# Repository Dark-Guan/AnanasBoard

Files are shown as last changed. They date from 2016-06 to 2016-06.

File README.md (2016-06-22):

# AnanasBoard
AnanasBoard is Designed for Stepper Closeloop Control.

<a rel="license" href="http://creativecommons.org/licenses/by/4.0/">
</a><br />本作品采用<a rel="license" href="http://creativecommons.org/licenses/by/4.0/">知识共享署名 4.0 国际许可协议</a>进行许可。

如果你认为我做的这些对你来说是有价值的, 并鼓励我进行更多开源和免费的开发. 那你可以资助我, 就算是一杯咖啡...

If you find my work useful and you want to encourage the development of more free resources, you can do it by donating...

<a rel="donate1" href="https://www.paypal.com/cgi-bin/webscr?cmd=_s-xclick&hosted_button_id=8GQHVZ7YR8NZE">
PalpayDonate</a>

<a rel="donate2" href="https://raw.githubusercontent.com/Dark-Guan/AnanasBoard/master/apcazu6ntbjy04py09.png">
Alipay</a>

##feature

1. AMS5600 and Quadrature Encoder Supported  
2. Intelligent Tuning of the Motor Current  
3. Up to 30Khz Pulse Input Supported  
4. Up to 60Khz Stepper Driver PWM with Trapezoid Acceleration  
5. Internal PID Speed Controller  

##driver
1. A4988 and Drv8825 supported.
2. PWM DA function supported.With the  Tale:
    *PWM frequence needs to be up to 10Khz*

| IC| divider resistance | Capacitance | 5V| 3.3V
| --- | --- | --- | --- | ---
| A4988 | 10KOhm | 0.1uf | 4.7KOhm | 10KOhm
| drv8825 | 10KOhm | 0.1uf | 2.7KOhm | 3.3KOhm

circuit: voltage division circuit with a Capacitance(0.1uf)  
More Info : _[A4988](http://www.allegromicro.com/~/media/Files/Datasheets/A4988-Datasheet.ashx?la=zh-CN) and [Drv8825](http://www.ti.com/lit/ds/symlink/drv8825.pdf)datasheet_.  

# Eagle

Eagle 7.2 Used

# SoftWare
https://git.oschina.net/GaryPillow/Ananas
## back up
https://github.com/Dark-Guan/Ananas

https://github.com/Dark-Guan/Ananas/tree/master/binary

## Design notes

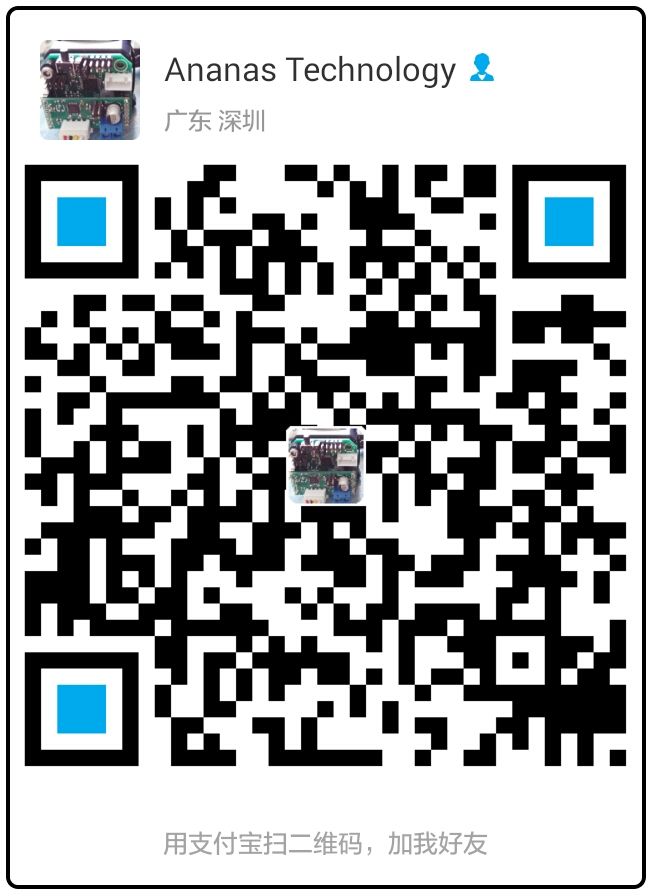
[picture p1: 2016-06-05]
apcazu6ntbjy04py09.png

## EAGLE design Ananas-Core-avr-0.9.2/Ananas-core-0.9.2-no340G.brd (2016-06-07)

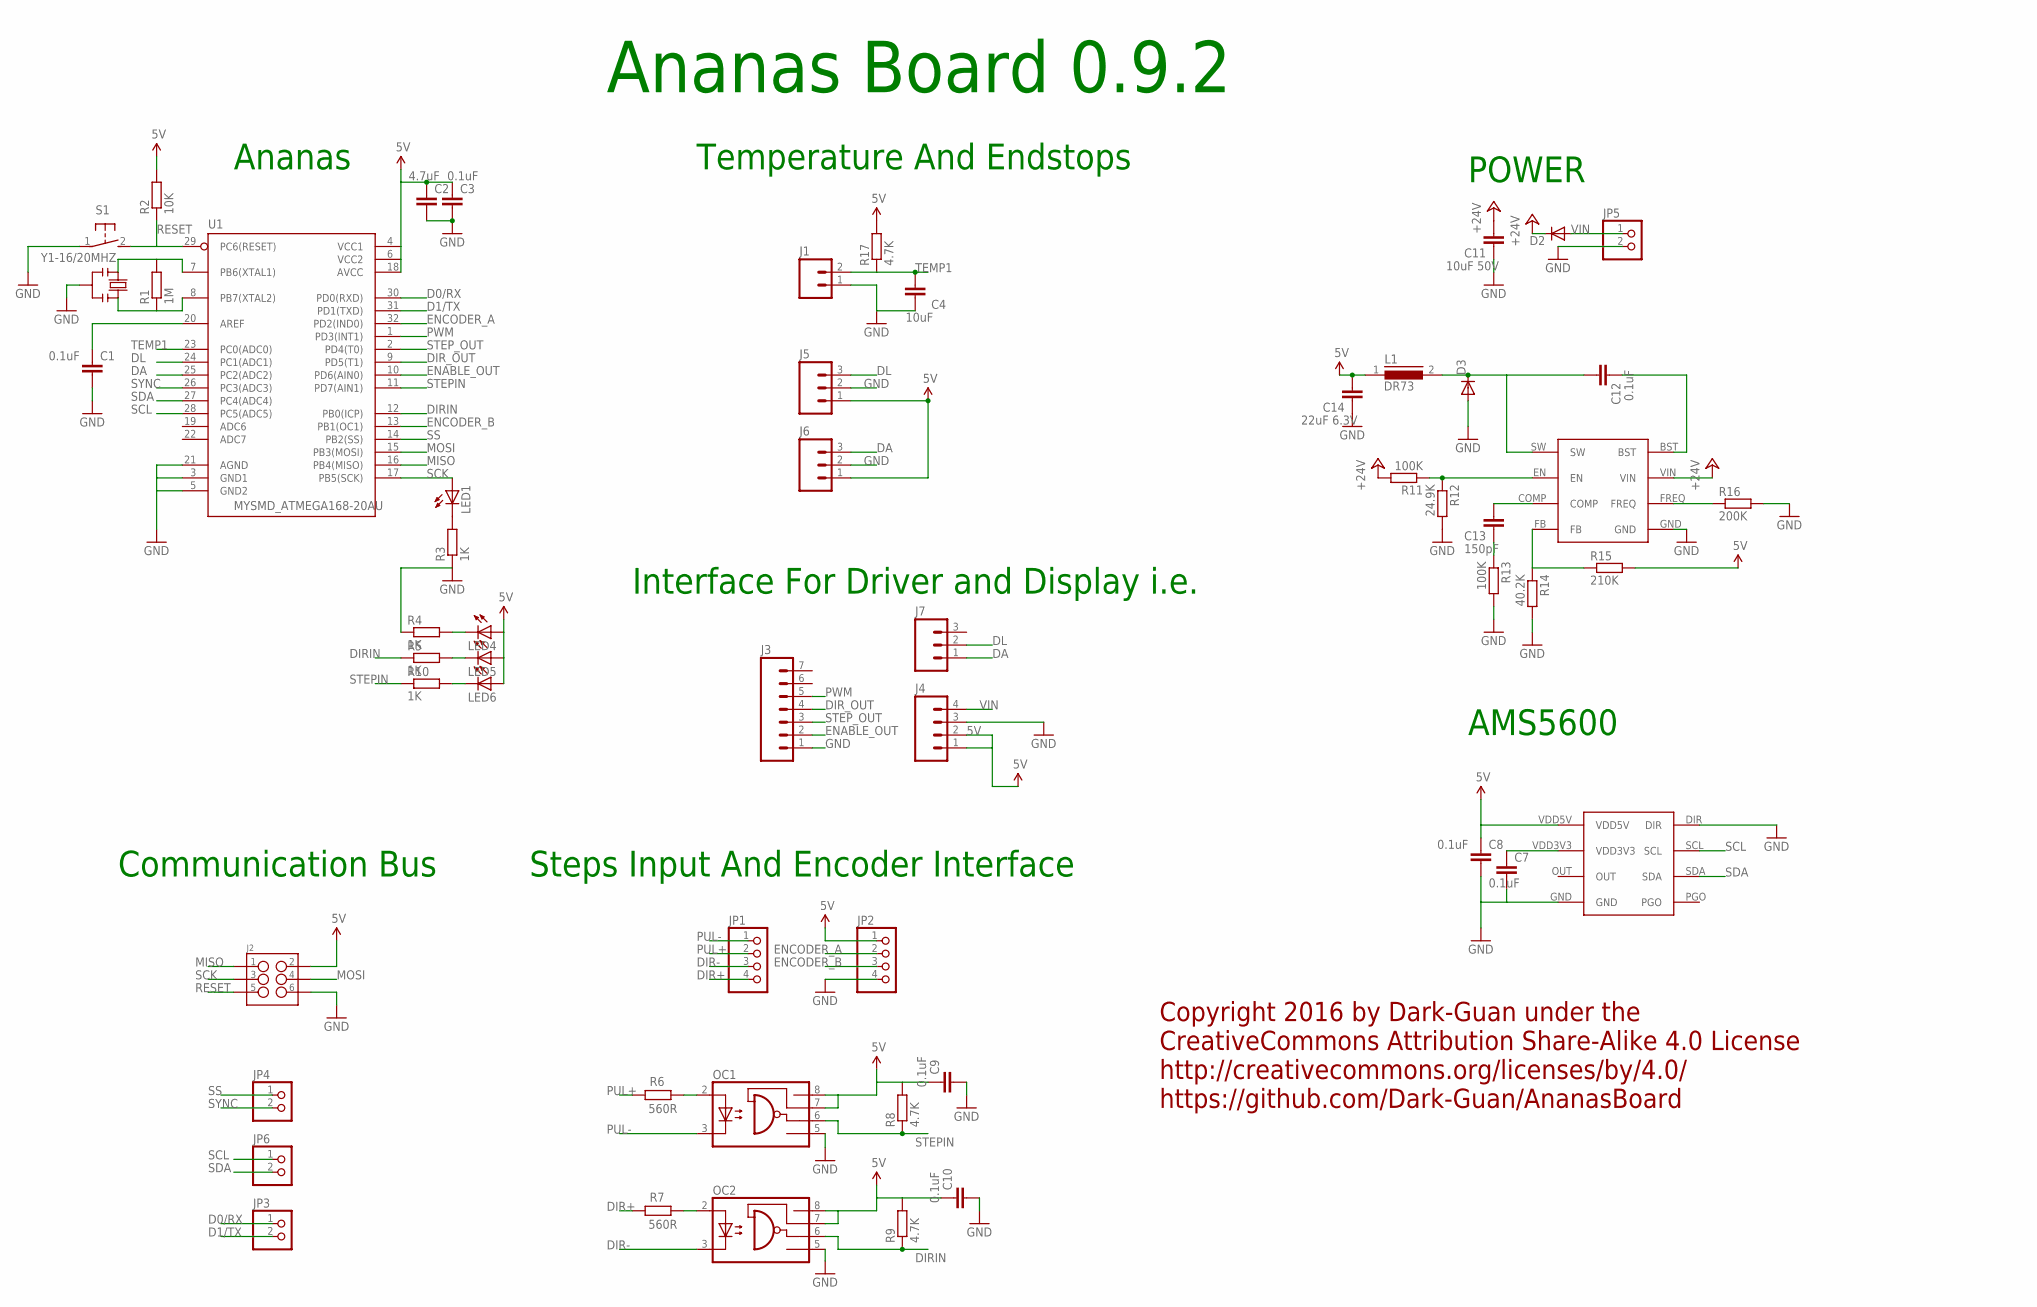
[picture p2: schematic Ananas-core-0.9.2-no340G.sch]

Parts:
C1, C3, C7, C8, C9, C10, C12: 0.1uF; C0603K
C2: 4.7uF; C0603K
C4: 10uF; C0603K
C11: 10uF 50V; C0805
C13: 150pF; C0603K
C14: 22uF 6.3V; C0805
D2, D3: DIODE_DIODE-SMB; DIODE_SMB
J1: M02PTH; 1X02
J2: M03X2NO_SILK; 2X3-NS
J3: M07; 1X07
J4: M04PTH; 1X04
J5, J6, J7: M03PTH; 1X03
JP1, JP2: PINHD-1X4/OCT; 1X04/OCT
JP3, JP4, JP5, JP6: PINHD-1X2/OCT; 1X02/OCT
L1: DR73
LED1, LED4, LED5, LED6: LEDCHIPLED_0603; CHIPLED_0603
MP1854: MP1584
OC1, OC2: OPTOCOUPLER_(2)_HCPL0600; OPTOCOUPLER_(2)_SOIC08
R1: 1M; R0603
R2: 10K; R0603
R3, R4, R5, R10: 1K; R0603
R6, R7: 560R; R0603
R8, R9, R17: 4.7K; R0603
R11, R13: 100K; R0603
R12: 24.9K; R0603
R14: 40.2K; R0603
R15: 210K; R0603
R16: 200K; R0603
S1: 31-XX; B3F-31XX
U1: MYSMD_ATMEGA168-20AU; MYSMD_QFP032
U$1: ARDUINO_AS5600
Y1-16/20MHZ: MYSMD2_RESONATORMU; MYSMD2_RESONATOR

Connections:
5V: C2.1, C3.1, C8.1, C9.1, C10.1, C14.2, J2.2, J4.1, J4.2, J5.1, J6.1, JP2.1, L1.1, LED4.A, LED5.A, LED6.A, OC1.7 (VE), OC1.8 (VCC), OC2.7 (VE), OC2.8 (VCC), R2.2, R8.2, R9.2, R15.2, R17.2, U1.4 (VCC1), U1.6 (VCC2), U1.18 (AVCC), U$1.VDD5V
+24V: C11.2, D2.C, MP1854.VIN, R11.2
D0/RX: JP3.1, U1.30 (PD0(RXD))
D1/TX: JP3.2, U1.31 (PD1(TXD))
DA: J6.3, J7.1, U1.25 (PC2(ADC2))
DIR+: JP1.4, R7.2
DIR-: JP1.3, OC2.3 (C)
DIRIN: OC2.6 (VO), R5.1, R9.1, U1.12 (PB0(ICP))
DIR_OUT: J3.4, U1.9 (PD5(T1))
DL: J5.3, J7.2, U1.24 (PC1(ADC1))
ENABLE_OUT: J3.2, U1.10 (PD6(AIN0))
ENCODER_A: JP2.2, U1.32 (PD2(IND0))
ENCODER_B: JP2.3, U1.13 (PB1(OC1))
GND: C1.2, C2.2, C3.2, C4.1, C7.2, C8.2, C9.2, C10.2, C11.1, C14.1, D3.A, J1.1, J2.6, J3.1, J4.3, J5.2, J6.2, JP2.4, JP5.2, MP1854.GND, OC1.5 (GND), OC2.5 (GND), R3.1, R4.1, R12.2, R13.2, R14.2, R16.2, S1.1, U1.3 (GND1), U1.5 (GND2), U1.21 (AGND), U$1.DIR, U$1.GND, Y1-16/20MHZ.2
MISO: J2.1, U1.16 (PB4(MISO))
MOSI: J2.4, U1.15 (PB3(MOSI))
unnamed: R1.2, U1.7 (PB6(XTAL1)), Y1-16/20MHZ.1
unnamed: R1.1, U1.8 (PB7(XTAL2)), Y1-16/20MHZ.3
unnamed: C1.1, U1.20 (AREF)
unnamed: OC1.2 (A), R6.1
unnamed: LED1.C, R3.2
unnamed: OC2.2 (A), R7.1
unnamed: C13.1, R13.1
unnamed: C7.1, U$1.VDD3V3
unnamed: MP1854.FREQ, R16.1
unnamed: C12.1, MP1854.BST
unnamed: C12.2, D3.C, L1.2, MP1854.SW
unnamed: MP1854.EN, R11.1, R12.1
unnamed: C13.2, MP1854.COMP
unnamed: MP1854.FB, R14.1, R15.1
unnamed: LED4.C, R4.2
unnamed: LED5.C, R5.2
unnamed: LED6.C, R10.2
PUL+: JP1.2, R6.2
PUL-: JP1.1, OC1.3 (C)
PWM: J3.5, U1.1 (PD3(INT1))
RESET: J2.5, R2.1, S1.2 (S), U1.29 (PC6(RESET))
SCK: J2.3, LED1.A, U1.17 (PB5(SCK))
SCL: JP6.1, U1.28 (PC5(ADC5)), U$1.SCL
SDA: JP6.2, U1.27 (PC4(ADC4)), U$1.SDA
SS: JP4.1, U1.14 (PB2(SS))
STEPIN: OC1.6 (VO), R8.1, R10.1, U1.11 (PD7(AIN1))
STEP_OUT: J3.3, U1.2 (PD4(T0))
SYNC: JP4.2, U1.26 (PC3(ADC3))
TEMP1: C4.2, J1.2, R17.1, U1.23 (PC0(ADC0))
VIN: D2.A, J4.4, JP5.1

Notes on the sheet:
Communication Bus
Steps Input And Encoder Interface
AMS5600
Interface For Driver and Display i.e.
Temperature And Endstops
POWER
Copyright 2016 by Dark-Guan under the CreativeCommons Attribution Share-Alike 4.0 License http://creativecommons.org/licenses/by/4.0/ https://github.com/Dark-Guan/AnanasBoard
Ananas Board 0.9.2
Ananas

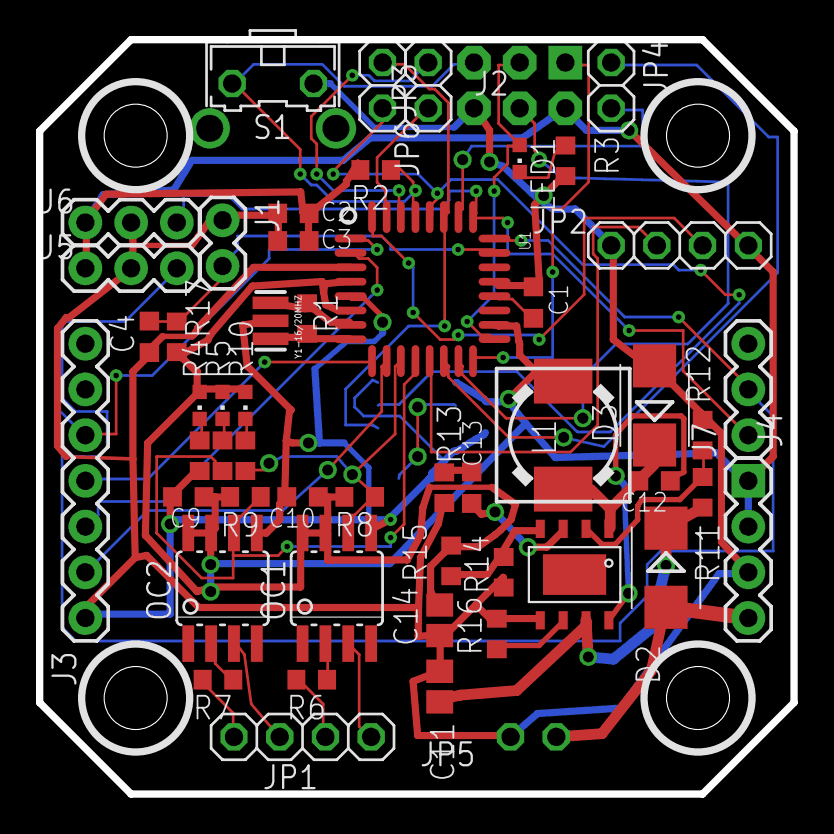
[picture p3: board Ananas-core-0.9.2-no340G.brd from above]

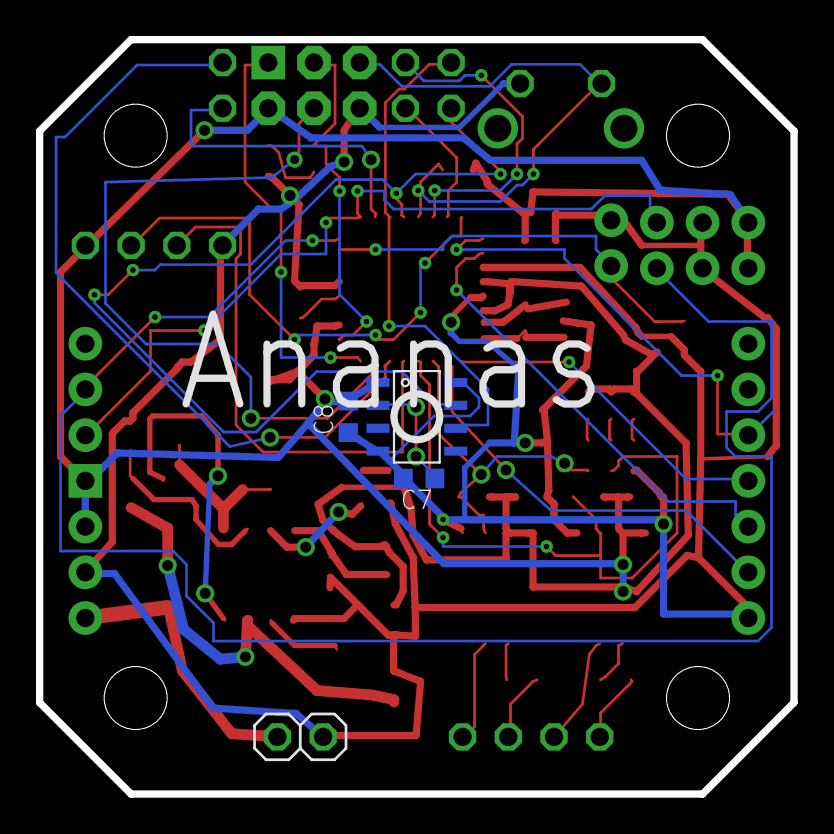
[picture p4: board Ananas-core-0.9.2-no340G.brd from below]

Board: 2 copper layers, 41.9 x 41.9 mm, 56 parts (4 on the bottom side), 46 nets.

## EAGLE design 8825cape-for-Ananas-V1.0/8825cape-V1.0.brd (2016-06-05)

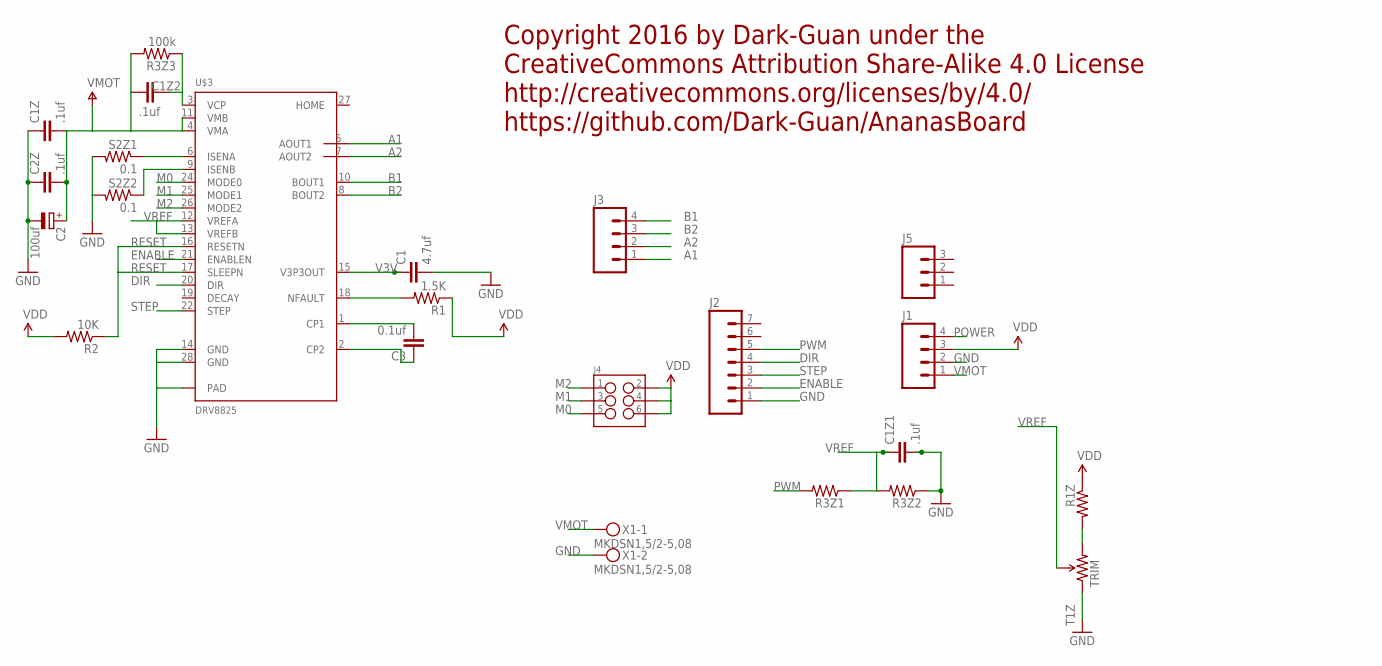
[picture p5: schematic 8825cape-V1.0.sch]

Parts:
C1: 4.7uf; 0402-CAP
C1Z, C1Z1, C1Z2, C2Z: .1uf; 0402-CAP
C2: 100uf; 153CLV-0605
C3: 0.1uf; 0402-CAP
J1, J3: M04PTH; 1X04
J2: M07; 1X07
J4: M03X2NO_SILK; 2X3-NS
J5: M03PTH; 1X03
R1: 1.5K; 0402-RES
R1Z, R3Z1, R3Z2: RESISTOR0402-RES; 0402-RES
R2: 10K; 0402-RES
R3Z3: 100k; 0402-RES
S2Z1, S2Z2: 0.1; 0805
T1Z: TRIM; TRIMPOT-3MM
U$3: DRV8825; HTSSOP28
X1: MKDSN1,5/2-5,08

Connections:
A1: J3.1, U$3.5 (AOUT1)
A2: J3.2, U$3.7 (AOUT2)
B1: J3.4, U$3.10 (BOUT1)
B2: J3.3, U$3.8 (BOUT2)
DIR: J2.4, U$3.20 (DIR)
ENABLE: J2.2, U$3.21 (ENABLEN)
GND: C1.2, C1Z.1, C1Z1.2, C2.-, C2Z.1, J1.2, J2.1, R3Z2.1, S2Z1.2, S2Z2.2, T1Z.1 (CCW), U$3.14 (GND), U$3.28 (GND), U$3.GND@10 (PAD), U$3.GND@11 (PAD), U$3.GND@12 (PAD), U$3.GND@13 (PAD), U$3.GND@14 (PAD), U$3.GND@15 (PAD), U$3.GND@16 (PAD), U$3.GND@17 (PAD), U$3.GND@18 (PAD), U$3.GND@19 (PAD), U$3.GND@20 (PAD), U$3.GND@21 (PAD), U$3.GND@22 (PAD), U$3.GND@23 (PAD), U$3.GND@24 (PAD), U$3.GND@25 (PAD), U$3.GND@26 (PAD), U$3.GND@27 (PAD), U$3.GND@28 (PAD), U$3.GND@29 (PAD), U$3.GND@30 (PAD), U$3.GND@PAD (PAD), X1.2
M0: J4.5, U$3.24 (MODE0)
M1: J4.3, U$3.25 (MODE1)
M2: J4.1, U$3.26 (MODE2)
unnamed: S2Z1.1, U$3.6 (ISENA)
unnamed: C1Z2.1, R3Z3.1, U$3.3 (VCP)
unnamed: C3.2, U$3.1 (CP1)
unnamed: S2Z2.1, U$3.9 (ISENB)
unnamed: C3.1, U$3.2 (CP2)
unnamed: R1.2, U$3.18 (NFAULT)
POWER: J1.4
PWM: J2.5, R3Z1.2
RESET: R2.1, U$3.16 (RESETN), U$3.17 (SLEEPN)
STEP: J2.3, U$3.22 (STEP)
V3V: C1.1, U$3.15 (V3P3OUT)
VDD: J1.3, J4.2, J4.4, J4.6, R1.1, R1Z.1, R2.2
VMOT: C1Z.2, C1Z2.2, C2.+, C2Z.2, J1.1, R3Z3.2, U$3.4 (VMA), U$3.11 (VMB), X1.1
VREF: C1Z1.1, R3Z1.1, R3Z2.2, T1Z.2 (WIPER), U$3.12 (VREFA), U$3.13 (VREFB)
ZREF2: R1Z.2, T1Z.3 (CW)

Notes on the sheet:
Copyright 2016 by Dark-Guan under the CreativeCommons Attribution Share-Alike 4.0 License http://creativecommons.org/licenses/by/4.0/ https://github.com/Dark-Guan/AnanasBoard

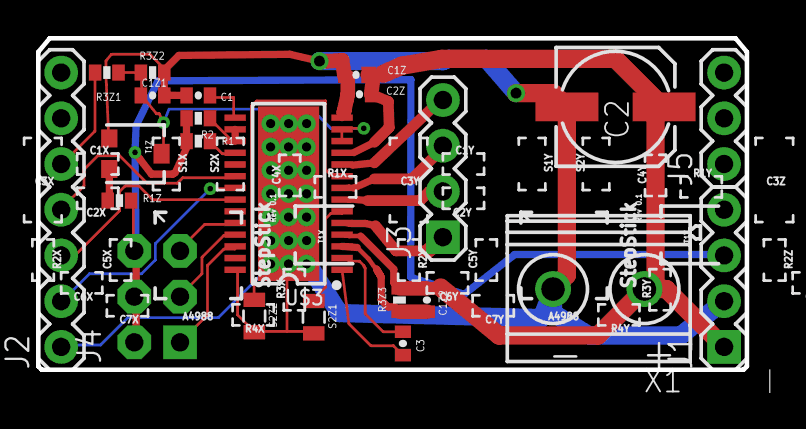
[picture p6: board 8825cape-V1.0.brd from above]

Board: 2 copper layers, 40.6 x 19.7 mm, 23 parts (0 on the bottom side), 24 nets.

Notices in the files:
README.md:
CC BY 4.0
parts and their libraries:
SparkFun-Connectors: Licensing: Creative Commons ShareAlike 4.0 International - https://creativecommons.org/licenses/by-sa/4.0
